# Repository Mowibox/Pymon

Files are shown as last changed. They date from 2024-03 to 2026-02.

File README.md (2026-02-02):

# Pymon

Game project developed with OpenCV and STM32 for the Image & Virtual Reality Workshop.

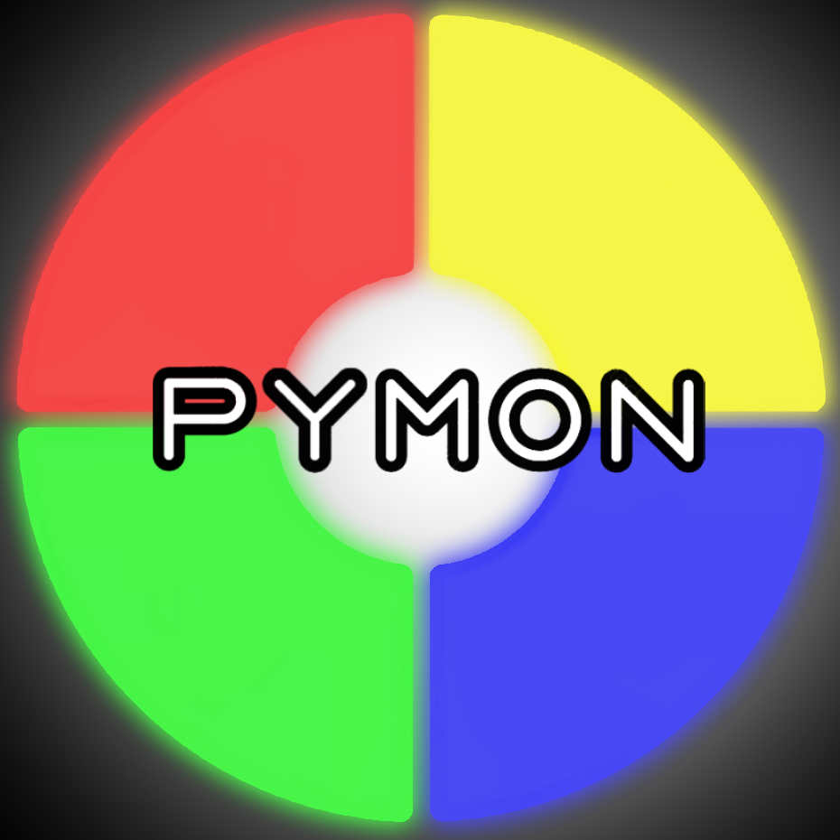
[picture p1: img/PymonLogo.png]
Pymon Logo


## About the game

Pymon is a Python derivative of the game Simon where the objective is to memorize and reproduce sequences of random colors.

The unique aspect of Pymon is that the game interface is created using the player's computer camera, and color selection is done directly on the screen by hand detection.

Serial communication is established with the game box to retrieve player inputs.

## How to play?

Clone this repository to your computer:

```bash
git clone https://github.com/Mowibox/Pymon.git
```

Connect the game device to your computer; a sound sequence should play if everything is working correctly.

Open the `main.py` file in the Python folder and install the libraries by using the requirements file:

```bash
pip install -r requirements.txt
```

Have fun!

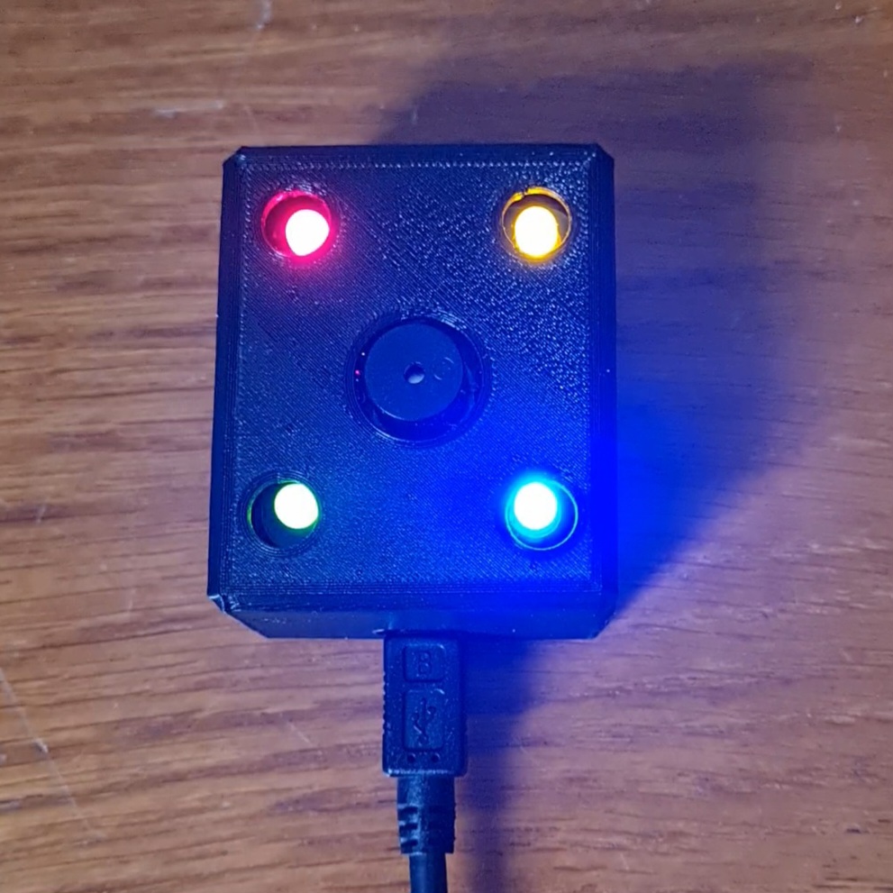
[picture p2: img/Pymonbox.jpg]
Pymon Game Box


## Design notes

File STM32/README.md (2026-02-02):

# STM32 Pymon

This directory houses the microcontroller part of Pymon.

## Configuration

For this project, we are using a NUCLEO F303K8 development board.

Serial communication takes place through the VCP port, on USART2 with a baud rate of 38400.

The pin configuration is as follows:

| Description | Morpho Pin | Arduino Pin | Configuration |
|---|---|---|---|
| Red LED | PA7 | A6 |  GPIO_Output  |
|  Yellow LED | PB0 | D3 |  GPIO_Output  |
|  Green LED  | PA1 | D8 |  GPIO_Output  |
| Blue LED  | PF1 | A1 |  GPIO_Output  |
| Buzzer | PA6 | A5 | TIM3_CH1 |

Channel 1 of Timer 3 is activated to generate a PWM signal, allowing the buzzer to be used.

The buzzer library and how to integrate it into a project are specified the following [repository](https://github.com/brapacz/stm32-buzzer)

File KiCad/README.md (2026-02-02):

# KiCad Pymon PCB

The electronic board of the Pymon game rests in this folder.

The PCB contains 4 LEDs and their associated resistors, a buzzer, and two female connectors for the NUCLEO F303K8 board.

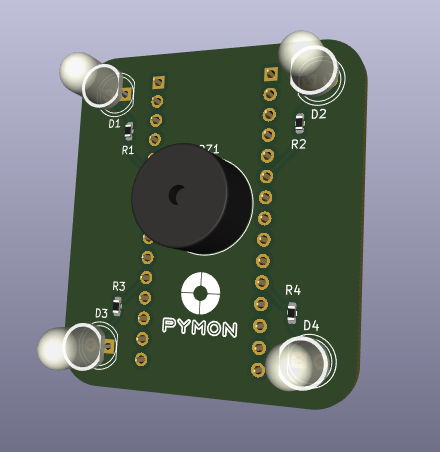
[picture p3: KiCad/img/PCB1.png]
Pymon PCB Face


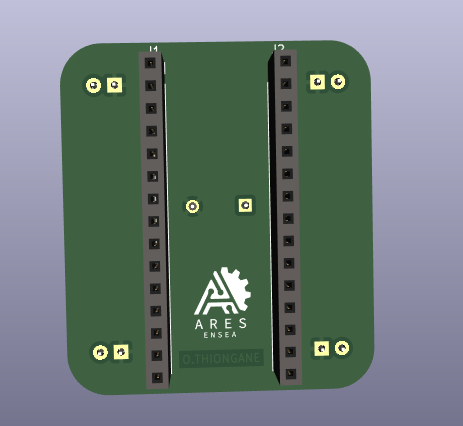
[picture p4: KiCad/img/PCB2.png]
Pymon PCB Bottom


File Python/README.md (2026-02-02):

# Python Pymon

In this directory lies the software part of Pymon. Camera and display (text, rectangles) management is done using the OpenCV library. To run this game, we use the MediaPipe library for real-time hand detection and tracking. The pyserial library allows us to communicate between our program and the STM32 connected via USB cable.

## Game Sections

### Menu

The menu allows us to access settings or start the game.

### Game

Buttons of 4 colors are displayed on the screen. The game prompts the player to watch the sequence of colors made on the device, then replicate it. Each successful level increases the sequence length by 1. Mistakes deduct life points until game over.

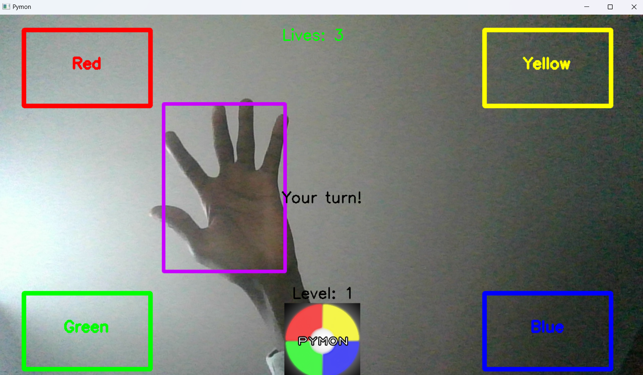
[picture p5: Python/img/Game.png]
Pymon Game


### Settings

Settings provide access to Score, Difficulty, and Player sections.

### Difficulty

Allows choosing between easy mode (each level's sequence remains identical to the previous one, with an additional random color) and hard mode (the sequence completely changes at each level).

### Score

This section allows the player to view their best score (i.e., the highest level reached). There's a separate best score for easy and hard modes.

### Player (Under development...)

Facial recognition could be added to register the current player. This would allow comparing scores between players.

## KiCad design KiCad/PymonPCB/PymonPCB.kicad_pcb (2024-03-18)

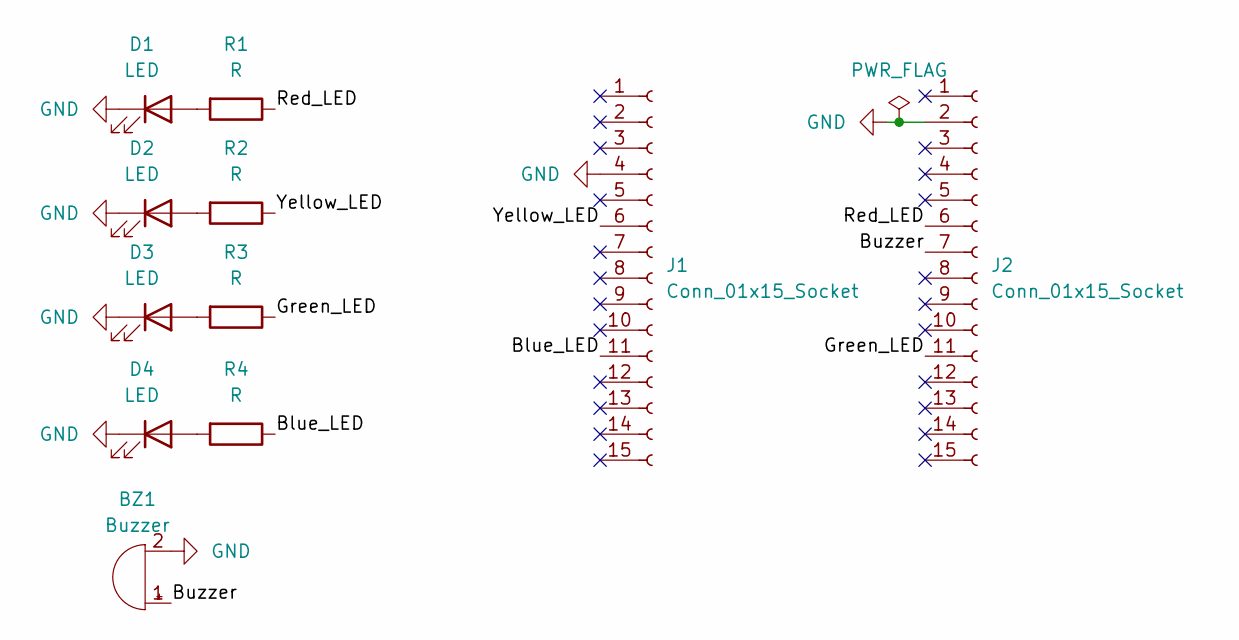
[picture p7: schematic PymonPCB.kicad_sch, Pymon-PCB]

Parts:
BZ1: Buzzer; MagneticBuzzer_ProSignal_ABT-410-RC
D1, D2, D3, D4: LED; LED_D5.0mm_Clear
J1, J2: Conn_01x15_Socket; PinSocket_1x15_P2.54mm_Vertical
R1, R2, R3, R4: R; R_0603_1608Metric

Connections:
/Blue_LED: J1.11, R4.1
/Buzzer: BZ1.1 (-), J2.7
/Green_LED: J2.11, R3.1
/Red_LED: J2.6, R1.1
/Yellow_LED: J1.6, R2.1
GND: BZ1.2 (+), D1.1 (K), D2.1 (K), D3.1 (K), D4.1 (K), J1.4, J2.2
unnamed: D1.2 (A), R1.2
unnamed: D2.2 (A), R2.2
unnamed: D3.2 (A), R3.2
unnamed: D4.2 (A), R4.2

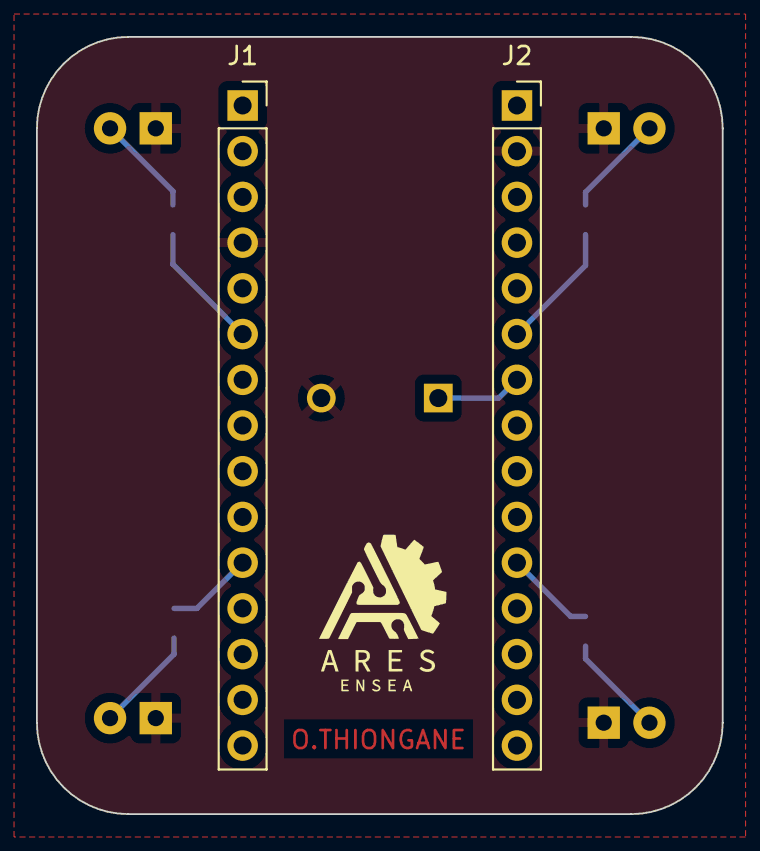
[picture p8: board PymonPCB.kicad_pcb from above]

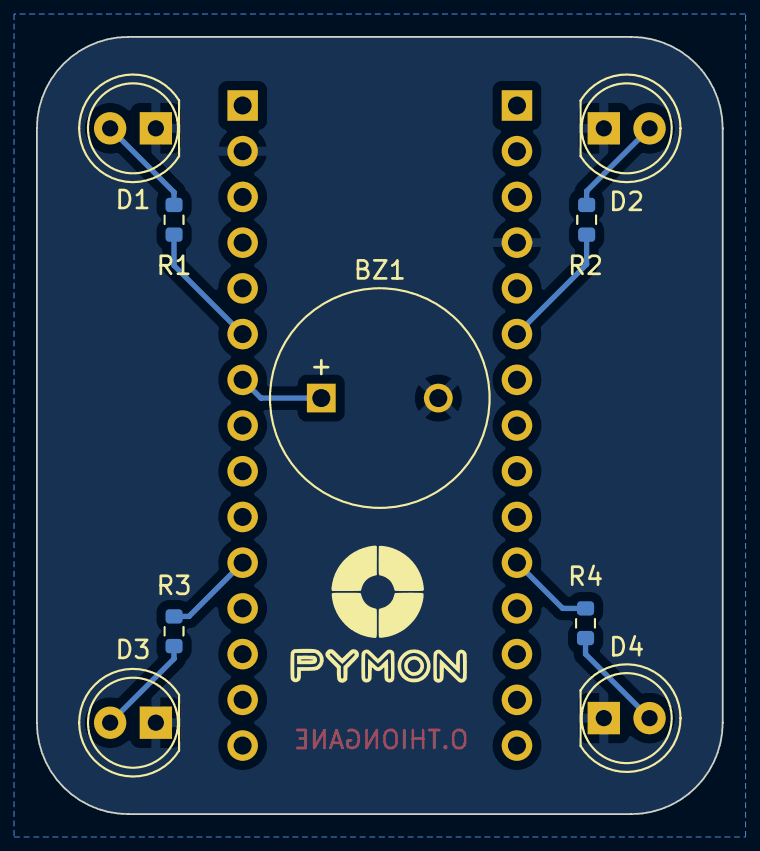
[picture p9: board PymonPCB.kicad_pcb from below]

Board: 2 copper layers, 38.1 x 43.2 mm, 11 parts (9 on the bottom side), 10 nets.

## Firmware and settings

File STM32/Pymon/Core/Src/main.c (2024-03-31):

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
/* Includes ------------------------------------------------------------------*/
#include "main.h"

/* USER CODE BEGIN Includes */
#include "buzzer.h"
#include "buzzer_tones.h"
/* USER CODE END Includes */

/* USER CODE BEGIN PTD */
Buzzer_HandleTypeDef hbuzzer;
/* USER CODE END PTD */

TIM_HandleTypeDef htim1;
TIM_HandleTypeDef htim3;

UART_HandleTypeDef huart2;

void SystemClock_Config(void);
static void MX_GPIO_Init(void);
static void MX_USART2_UART_Init(void);
static void MX_TIM1_Init(void);
static void MX_TIM3_Init(void);
/**
  * @brief  The application entry point.
  * @retval int
  */
int main(void)
{
  /* MCU Configuration--------------------------------------------------------*/

  /* Reset of all peripherals, Initializes the Flash interface and the Systick. */
  HAL_Init();

  /* Configure the system clock */
  SystemClock_Config();

  /* Initialize all configured peripherals */
  MX_GPIO_Init();
  MX_USART2_UART_Init();
  MX_TIM1_Init();
  MX_TIM3_Init();
  /* USER CODE BEGIN 2 */

  //Buzzer configuration
  uint8_t buf;
  Buzzer_InitTypeDef buzzerConfig;
  buzzerConfig.channel = TIM_CHANNEL_1;
  buzzerConfig.timer = &htim3;
  buzzerConfig.timerClockFreqHz = HAL_RCC_GetPCLK2Freq(); // NOTE: this should be freq of timer, not frequency of peripheral clock
  Buzzer_Init(&hbuzzer, &buzzerConfig);
  Buzzer_Start(&hbuzzer);

  GPIO_TypeDef * Red_GPIO = GPIOF;
  uint16_t Red_PIN = GPIO_PIN_1;

  GPIO_TypeDef * Yellow_GPIO = GPIOA;
  uint16_t Yellow_PIN = GPIO_PIN_1;

  GPIO_TypeDef * Green_GPIO = GPIOB;
  uint16_t Green_PIN = GPIO_PIN_0;

  GPIO_TypeDef * Blue_GPIO = GPIOA;
  uint16_t Blue_PIN = GPIO_PIN_7;


  //Boot sequence
  HAL_GPIO_WritePin(Red_GPIO, Red_PIN, GPIO_PIN_SET);
  HAL_GPIO_WritePin(Yellow_GPIO, Yellow_PIN, GPIO_PIN_RESET);
  HAL_GPIO_WritePin(Green_GPIO, Green_PIN, GPIO_PIN_RESET);
  HAL_GPIO_WritePin(Blue_GPIO, Blue_PIN, GPIO_PIN_RESET);
  Buzzer_Note(&hbuzzer, NOTE_C4);
  HAL_Delay(200);

  HAL_GPIO_WritePin(Red_GPIO, Red_PIN, GPIO_PIN_RESET);
  HAL_GPIO_WritePin(Yellow_GPIO, Yellow_PIN, GPIO_PIN_SET);
  HAL_GPIO_WritePin(Green_GPIO, Green_PIN, GPIO_PIN_RESET);
  HAL_GPIO_WritePin(Blue_GPIO, GPIO_PIN_7, GPIO_PIN_RESET);
  Buzzer_Note(&hbuzzer, NOTE_D4);
  HAL_Delay(200);

  HAL_GPIO_WritePin(Red_GPIO, Red_PIN, GPIO_PIN_RESET);
  HAL_GPIO_WritePin(Yellow_GPIO, Yellow_PIN, GPIO_PIN_RESET);
  HAL_GPIO_WritePin(Green_GPIO, Green_PIN, GPIO_PIN_SET);
  HAL_GPIO_WritePin(Blue_GPIO, Blue_PIN, GPIO_PIN_RESET);
  Buzzer_Note(&hbuzzer, NOTE_E4);
  HAL_Delay(200);

  HAL_GPIO_WritePin(Red_GPIO, Red_PIN, GPIO_PIN_RESET);
  HAL_GPIO_WritePin(Yellow_GPIO, Yellow_PIN, GPIO_PIN_RESET);
  HAL_GPIO_WritePin(Green_GPIO, Green_PIN, GPIO_PIN_RESET);
  HAL_GPIO_WritePin(Blue_GPIO, Blue_PIN, GPIO_PIN_SET);
  Buzzer_Note(&hbuzzer, NOTE_F4);
  HAL_Delay(200);

  HAL_GPIO_WritePin(Red_GPIO, Red_PIN, GPIO_PIN_SET);
  HAL_GPIO_WritePin(Yellow_GPIO, Yellow_PIN, GPIO_PIN_RESET);
  HAL_GPIO_WritePin(Green_GPIO, Green_PIN, GPIO_PIN_RESET);
  HAL_GPIO_WritePin(Blue_GPIO, Blue_PIN, GPIO_PIN_RESET);
  Buzzer_Note(&hbuzzer, NOTE_G4);
  HAL_Delay(200);

  HAL_GPIO_WritePin(Red_GPIO, Red_PIN, GPIO_PIN_SET);
  HAL_GPIO_WritePin(Yellow_GPIO, Yellow_PIN, GPIO_PIN_SET);
  HAL_GPIO_WritePin(Green_GPIO, Green_PIN, GPIO_PIN_RESET);
  HAL_GPIO_WritePin(Blue_GPIO, Blue_PIN, GPIO_PIN_RESET);
  Buzzer_Note(&hbuzzer, NOTE_A4);
  HAL_Delay(200);

  HAL_GPIO_WritePin(Red_GPIO, Red_PIN, GPIO_PIN_SET);
  HAL_GPIO_WritePin(Yellow_GPIO, Yellow_PIN, GPIO_PIN_SET);
  HAL_GPIO_WritePin(Green_GPIO, Green_PIN, GPIO_PIN_SET);
  HAL_GPIO_WritePin(Blue_GPIO, Blue_PIN, GPIO_PIN_RESET);
  Buzzer_Note(&hbuzzer, NOTE_B4);
  HAL_Delay(200);

  HAL_GPIO_WritePin(Red_GPIO, Red_PIN, GPIO_PIN_SET);
  HAL_GPIO_WritePin(Yellow_GPIO, Yellow_PIN, GPIO_PIN_SET);
  HAL_GPIO_WritePin(Green_GPIO, Green_PIN, GPIO_PIN_SET);
  HAL_GPIO_WritePin(Blue_GPIO, Blue_PIN, GPIO_PIN_SET);
  Buzzer_Note(&hbuzzer, NOTE_C5);
  HAL_Delay(500);

  HAL_GPIO_WritePin(Red_GPIO, Red_PIN, GPIO_PIN_RESET);
  HAL_GPIO_WritePin(Yellow_GPIO, Yellow_PIN, GPIO_PIN_RESET);
  HAL_GPIO_WritePin(Green_GPIO, Green_PIN, GPIO_PIN_RESET);
  HAL_GPIO_WritePin(Blue_GPIO, Blue_PIN, GPIO_PIN_RESET);
  Buzzer_Note(&hbuzzer, 0);


  /* USER CODE END 2 */

  /* Infinite loop */
  /* USER CODE BEGIN WHILE */
  while (1)
  {


	  //Data reception
	  HAL_UART_Receive(&huart2, &buf, 1, 1000);

	  //Red color
	  if (buf == 'r'){
		  HAL_GPIO_WritePin(Red_GPIO, Red_PIN, GPIO_PIN_SET);
		  Buzzer_Note(&hbuzzer, NOTE_C4);
	  }
	  //Yellow color
	  else if (buf == 'y'){
		  HAL_GPIO_WritePin(Yellow_GPIO, Yellow_PIN, GPIO_PIN_SET);
		  Buzzer_Note(&hbuzzer, NOTE_D4);
	  }
	  //Green color
	  else if (buf == 'g'){
		  HAL_GPIO_WritePin(Green_GPIO, Green_PIN, GPIO_PIN_SET);
		  Buzzer_Note(&hbuzzer, NOTE_E4);
	  }
	  //Blue color
	  else if (buf == 'b'){
		  HAL_GPIO_WritePin(Blue_GPIO, Blue_PIN, GPIO_PIN_SET);
		  Buzzer_Note(&hbuzzer, NOTE_F4);
	  }
	  //None
	  else if (buf == 'n'){
		  HAL_GPIO_WritePin(Red_GPIO, Red_PIN, GPIO_PIN_RESET);
		  HAL_GPIO_WritePin(Yellow_GPIO, Yellow_PIN, GPIO_PIN_RESET);
		  HAL_GPIO_WritePin(Green_GPIO, Green_PIN, GPIO_PIN_RESET);
		  HAL_GPIO_WritePin(Blue_GPIO, Blue_PIN, GPIO_PIN_RESET);
		  Buzzer_Note(&hbuzzer, 0);
	  }

	  //Main menu sequence
	  else if (buf == 'm'){
		  HAL_GPIO_WritePin(Red_GPIO, Red_PIN, GPIO_PIN_SET);
		  HAL_GPIO_WritePin(Yellow_GPIO, Yellow_PIN, GPIO_PIN_RESET);
		  HAL_GPIO_WritePin(Green_GPIO, Green_PIN, GPIO_PIN_RESET);
		  HAL_GPIO_WritePin(Blue_GPIO, Blue_PIN, GPIO_PIN_RESET);
		  HAL_Delay(250);

		  HAL_GPIO_WritePin(Red_GPIO, Red_PIN, GPIO_PIN_RESET);
		  HAL_GPIO_WritePin(Yellow_GPIO, Yellow_PIN, GPIO_PIN_SET);
		  HAL_GPIO_WritePin(Green_GPIO, Green_PIN, GPIO_PIN_RESET);
		  HAL_GPIO_WritePin(Blue_GPIO, Blue_PIN, GPIO_PIN_RESET);
		  HAL_Delay(250);

		  HAL_GPIO_WritePin(Red_GPIO, Red_PIN, GPIO_PIN_RESET);
		  HAL_GPIO_WritePin(Yellow_GPIO, Yellow_PIN, GPIO_PIN_RESET);
		  HAL_GPIO_WritePin(Green_GPIO, Green_PIN, GPIO_PIN_SET);
		  HAL_GPIO_WritePin(Blue_GPIO, Blue_PIN, GPIO_PIN_RESET);
		  HAL_Delay(250);

		  HAL_GPIO_WritePin(Red_GPIO, Red_PIN, GPIO_PIN_RESET);
		  HAL_GPIO_WritePin(Yellow_GPIO, Yellow_PIN, GPIO_PIN_RESET);
		  HAL_GPIO_WritePin(Green_GPIO, Green_PIN, GPIO_PIN_RESET);
		  HAL_GPIO_WritePin(Blue_GPIO, Blue_PIN, GPIO_PIN_SET);
		  HAL_Delay(250);

		  HAL_GPIO_WritePin(Red_GPIO, Red_PIN, GPIO_PIN_RESET);
		  HAL_GPIO_WritePin(Yellow_GPIO, Yellow_PIN, GPIO_PIN_RESET);
		  HAL_GPIO_WritePin(Green_GPIO, Green_PIN, GPIO_PIN_SET);
		  HAL_GPIO_WritePin(Blue_GPIO, Blue_PIN, GPIO_PIN_RESET);
		  HAL_Delay(250);

		  HAL_GPIO_WritePin(Red_GPIO, Red_PIN, GPIO_PIN_RESET);
		  HAL_GPIO_WritePin(Yellow_GPIO, Yellow_PIN, GPIO_PIN_SET);
		  HAL_GPIO_WritePin(Green_GPIO, Green_PIN, GPIO_PIN_RESET);
		  HAL_GPIO_WritePin(Blue_GPIO, Blue_PIN, GPIO_PIN_RESET);
		  HAL_Delay(250);

		  HAL_GPIO_WritePin(Red_GPIO, Red_PIN, GPIO_PIN_SET);
		  HAL_GPIO_WritePin(Yellow_GPIO, Yellow_PIN, GPIO_PIN_RESET);
		  HAL_GPIO_WritePin(Green_GPIO, Green_PIN, GPIO_PIN_RESET);
		  HAL_GPIO_WritePin(Blue_GPIO, Blue_PIN, GPIO_PIN_RESET);
		  HAL_Delay(50);

	  }


    /* USER CODE END WHILE */

    /* USER CODE BEGIN 3 */
  }
  /* USER CODE END 3 */
}

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


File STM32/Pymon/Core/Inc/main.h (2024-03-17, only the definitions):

#define MCO_Pin GPIO_PIN_0
#define MCO_GPIO_Port GPIOF
#define Blue_LED_Pin GPIO_PIN_1
#define Blue_LED_GPIO_Port GPIOF
#define Green_LED_Pin GPIO_PIN_1
#define Green_LED_GPIO_Port GPIOA
#define VCP_TX_Pin GPIO_PIN_2
#define VCP_TX_GPIO_Port GPIOA
#define Red_LED_Pin GPIO_PIN_7
#define Red_LED_GPIO_Port GPIOA
#define Yellow_LED_Pin GPIO_PIN_0
#define Yellow_LED_GPIO_Port GPIOB
#define BUZZER_Pin GPIO_PIN_8
#define BUZZER_GPIO_Port GPIOA
#define SWDIO_Pin GPIO_PIN_13
#define SWDIO_GPIO_Port GPIOA
#define SWCLK_Pin GPIO_PIN_14
#define SWCLK_GPIO_Port GPIOA
#define VCP_RX_Pin GPIO_PIN_15
#define VCP_RX_GPIO_Port GPIOA

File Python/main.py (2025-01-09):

"""
    @file        main.py
    @author      Mowibox (Ousmane THIONGANE)
    @brief       Game project developed with OpenCV and STM32 for the Image & Virtual Reality Workshop
    @version     2.0
    @date        2024-04-01
    
"""

# Imports
import time
from utils import *
from params import * 
from game_classes import *
from game_elements import *


def main():
    global max_level_easy, hard, gameState, numberOfLives, canPlay, FRAME_HEIGHT
    global max_level_hard, level, lifeColor, listAppend, time_elapsed, FRAME_WIDTH

    ser = find_box_port()
    mp_hands = mp.solutions.hands
    hands = mp_hands.Hands(max_num_hands=1, 
                        min_detection_confidence=0.6, 
                        min_tracking_confidence=0.6)

    scene = cv2.VideoCapture(0)

    scene.set(cv2.CAP_PROP_FRAME_WIDTH, FRAME_WIDTH)  
    scene.set(cv2.CAP_PROP_FRAME_HEIGHT, FRAME_HEIGHT)

    while scene.isOpened():
        ret, frame = scene.read()
        if not ret:
            break

        frame = cv2.flip(frame, 1)

        width, height, _ = frame.shape
        if (int(width), int(height)) != (FRAME_WIDTH, FRAME_HEIGHT):
            frame = cv2.resize(frame, (FRAME_WIDTH, FRAME_HEIGHT))

        frame, hand_rect = detect_hands(frame, mp_hands, hands)

    # ========================= Menu ===========================

        if gameState == GameState.MENU:
            StartButton.draw(frame)
            SettingsButton.draw(frame)

            if hand_rect is not None:
                if StartButton.intersects(hand_rect):
                    ser.write(ColorBox.NONE.value)
                    StartButton.draw(frame, ColorBGR.PINK) 
                    if time_elapsed is None:
                        time_elapsed = time.time()  
                    elif time.time() - time_elapsed > 2:
                        time_elapsed = None  
                        gameState = GameState.PLAYING 
                else:
                    StartButton.draw(frame, ColorBGR.BLACK)  
            else:
                ser.write(ColorBox.MULTI.value)

            if hand_rect is not None:
                if SettingsButton.intersects(hand_rect):
                    ser.write(ColorBox.NONE.value)
                    SettingsButton.draw(frame, ColorBGR.PINK)
                    if time_elapsed is None:
                        time_elapsed = time.time()  
                    elif time.time() - time_elapsed > 2:
                        time_elapsed = None  
                        gameState = GameState.SETTINGS  
                else:
                    SettingsButton.draw(frame)       
            else:
                time_elapsed = None
                ser.write(ColorBox.MULTI.value)

    # ================== Observation sequence ==================

        if gameState == GameState.PLAYING and not(canPlay): 
            frame = np.zeros_like(frame)
            RedButton.draw(frame, ColorBGR.RED)
            YellowButton.draw(frame, ColorBGR.YELLOW)
            GreenButton.draw(frame, ColorBGR.GREEN)
            BlueButton.draw(frame, ColorBGR.BLUE)
            gameText.update_color(ColorBGR.WHITE)
            gameText.update_text("Watch the light sequence...")
            LevelText.update_text(f"Level: {level}")
            livesText.update_text(f"Lives: {numberOfLives}")
            livesText.update_color(lifeColor)
            livesText.draw(frame)
            LevelText.draw(frame)
            gameText.draw(frame)

            # Create the sequence to be performed
            if time_elapsed is None:
                    ser.write(ColorBox.NONE.value)
                    time_elapsed = time.time()  
            elif time.time() - time_elapsed > 3:  
                time_elapsed = None
                if hard or level == 1:
                    memoryList = generateSequence(level)
                for i in range(len(memoryList)):
                    ser.write(memoryList[i])
                    time.sleep(0.6)
                    ser.write(ColorBox.NONE.value)
                    time.sleep(0.6)
                playerList = []
                canPlay = True
                
    # ======================= Playing ==========================

        if gameState == GameState.PLAYING and canPlay: 
            RedButton.draw(frame, ColorBGR.RED)
            YellowButton.draw(frame, ColorBGR.YELLOW)
            GreenButton.draw(frame, ColorBGR.GREEN)
            BlueButton.draw(frame, ColorBGR.BLUE)
            LevelText.update_text(f"Level: {level}")
            livesText.update_text(f"Lives: {numberOfLives}")
            livesText.update_color(lifeColor)
            livesText.draw(frame)
            LevelText.draw(frame)

            status = checkGameState(playerList, memoryList) 
            if status == 1:
                if time_elapsed is None:
                    time_elapsed = time.time()  
                elif time.time() - time_elapsed > 0.3:  
                    time_elapsed = None
                    gameState = GameState.LEVEL_COMPLETE
            elif status == 2:
                numberOfLives-=1
                if numberOfLives <= 0: 
                    gameState = GameState.GAME_OVER
                else:
                    gameState = GameState.LEVEL_FAILURE
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

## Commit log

2024-03-17 Game first version
    [PymonPCB.kicad_pcb, PymonPCB.kicad_sch]
2024-03-17 First update
    [PymonPCB.kicad_pcb, PymonPCB.kicad_sch]
2024-03-18 PCB update & Code correction
    [main.c]
2024-03-18 Adding Settings buttons
    [PymonPCB-B_Cu.gbr, PymonPCB-B_Mask.gbr, PymonPCB-B_Paste.gbr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]
2024-03-26 COM Port update & LED update
2024-03-31 Score Button Update
2024-03-31 Renaming Led Pins
2024-04-03 Image update
    [PymonPCB-B_Cu.gbr, PymonPCB-B_Mask.gbr, PymonPCB-B_Paste.gbr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]
2026-02-02 Update buzzer pin configuration in README.md

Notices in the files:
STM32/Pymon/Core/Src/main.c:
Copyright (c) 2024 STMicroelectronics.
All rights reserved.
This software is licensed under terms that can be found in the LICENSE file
